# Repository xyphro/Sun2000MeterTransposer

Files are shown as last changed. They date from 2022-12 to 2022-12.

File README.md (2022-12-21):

# Sun2000MeterTransposer

-> Enable other Smartmeters like SDM630 to connect to Huawei Sun2000 and look like DTSU-666.

This was my solution to address the fact, that DTSU-666 and its variants availability was "null".

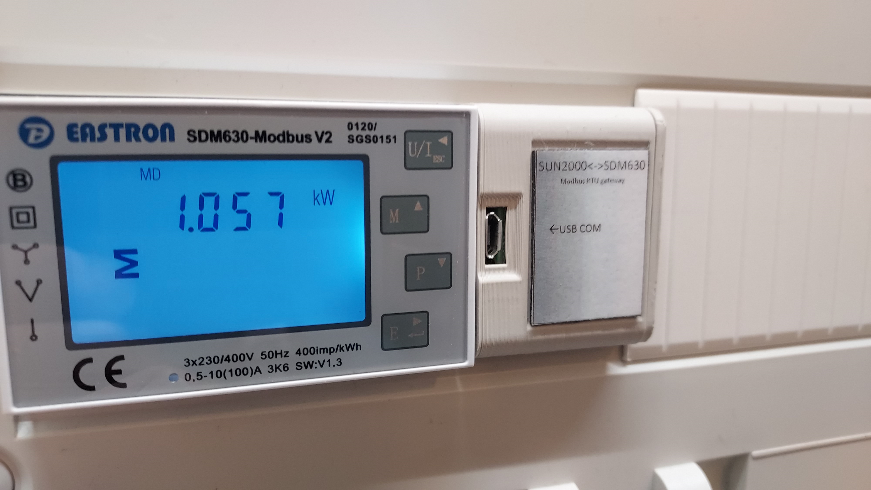
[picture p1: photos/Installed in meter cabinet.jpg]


It works rock solid since several months without a single interruption.

The project is based on RP2040 Raspberry pi Zero module. It will work on the Wifi variant too, but there is no network access enabled.

Note: I did not document the HW very well (yet), but want to share it still with the community. Build it at your own risk. The pinning of the 2 UART channels can be seen in s2kserver.py module (or schematic).

Warning: This project works with high voltage AC supply. You risk killing yourself, your family and friends, your pets. Take care and only work with line voltages when you are experienced in how much pain it causes to touch 230V :-)

# Folder structure

- hw: contains schematic / PCB in Eagle format.
- src: Micropython sourcecode - can be directly uploaded to RP2040 module using e.g. Thony IDE
- DinRainHousing: STL files for the 3D printed Dinrail housing
- photos: Some pictures of the actual build as inspiration

# Adjustments to other meters

Copy file sdm630.py and rename it to your meter name. Adjust it, such that the equivalent registers of your meter are read out and written to s2k module registers.
Within file s2kserver.py:
- You might need to change the UART settings like baudrate, parity in s2kserver during instatiation of uModBusSerial module.
- change ```from sdm630 import *``` to your module name

# Sourcecode orientation

main.py purpose is only to start s2kserver.py.
s2kserver instantiates 2 threads to server requests from Sun2000 inverter and poll SDM630 meter continously.

# Credits

Credits go to:
- uModbus [1] project. I changed the file slightly and included all dependencies within the src folder. Main modifications were done for speed/latency purposes
- DTSU666-Modbus [2] project: This project was of major support for the idea and to get register details. 
- GitHub user salakrzy
- Kai for testing it in endless debug sessions remotely whilr I was still busy ibstalling my solar installation and could not test myself
- Radek for making and providing his Chint DTSU666 module

# Compatibility

Tested with sun2000 3 phase 10kW inverters and proven working with spc147 and 148 firmware versions. As of now there is no newer one available.

# Updates

## 21st December 2022: 

Github user Radek made a module to support CHINT DTSU666 electricity meter (dtsu666.py). Thanks a lot for sharing it!

To make use of it adjust the settings within the user configurable settings in the file s2kserver.py.

Note that Chint DTSU666 usually uses those UART settings unless you configured it manually differently:

```
METER_UART_BAUDRATE = 9600
METER_UART_BITS     = 8
METER_UART_PARITY   = None
METER_UART_STOPBITS = 2
```

[1] https://github.com/pycom/pycom-modbus/tree/master/uModbus

[2] https://github.com/elfabriceu/DTSU666-Modbus

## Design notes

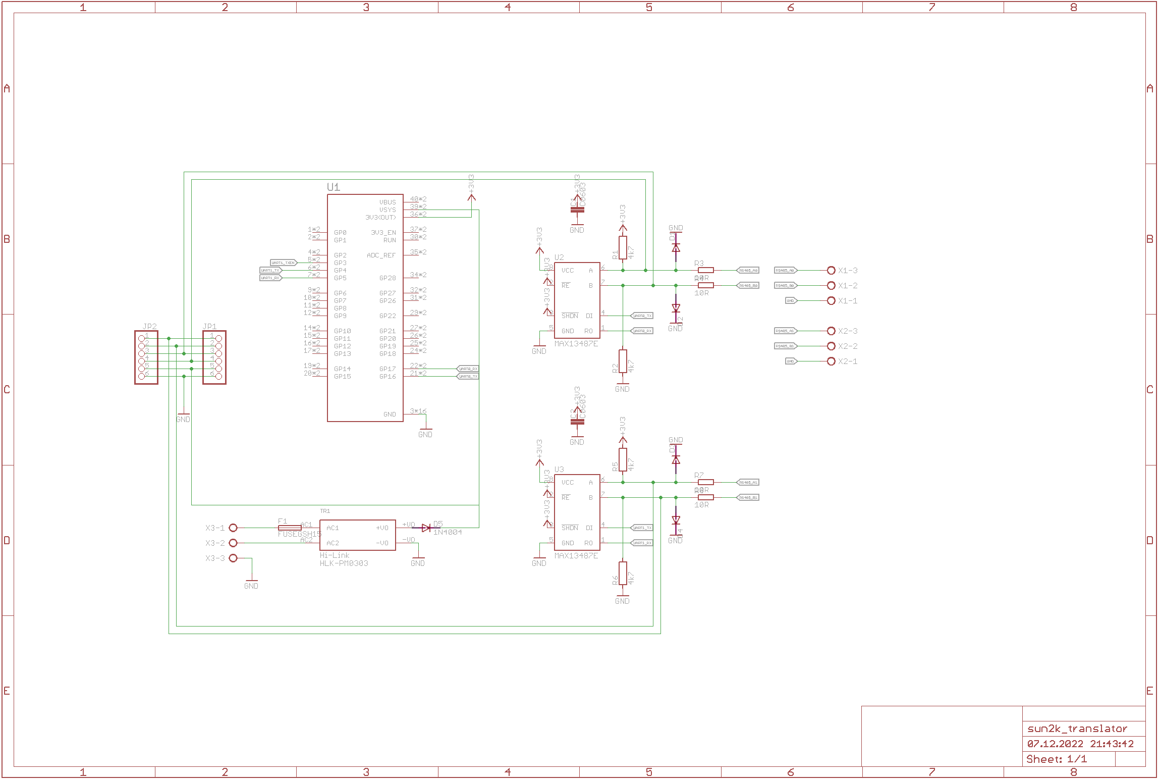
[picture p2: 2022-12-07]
hw/Schematic.png

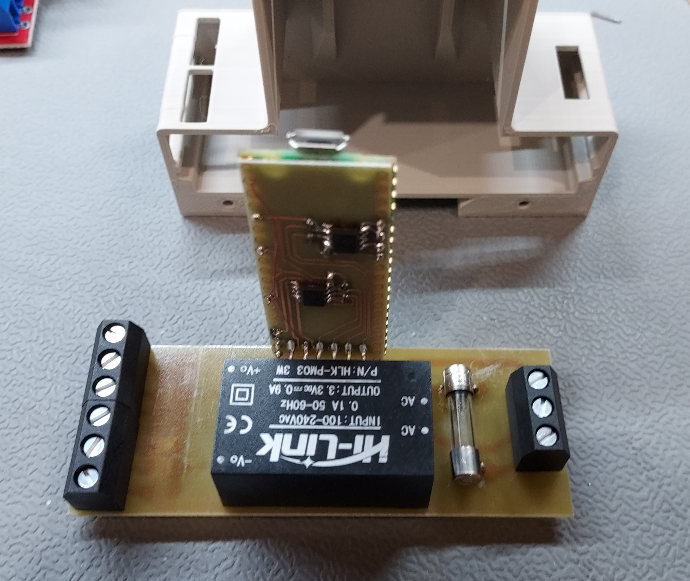
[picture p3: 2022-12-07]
photos/pcb1.jpg

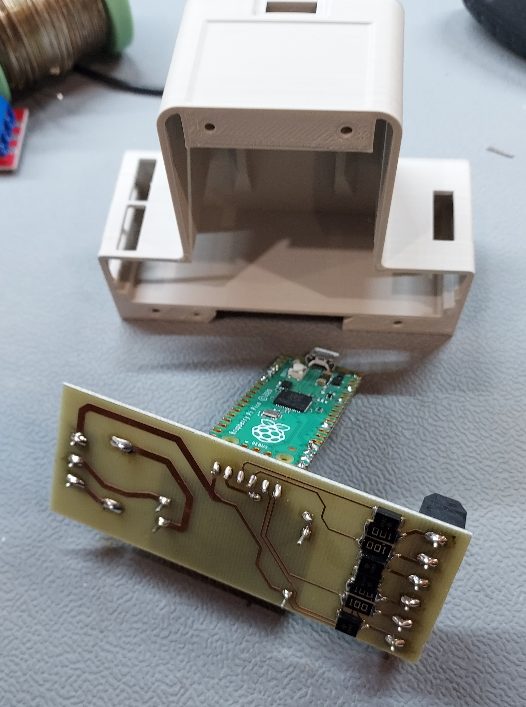
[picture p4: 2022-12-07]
photos/pcb2.jpg

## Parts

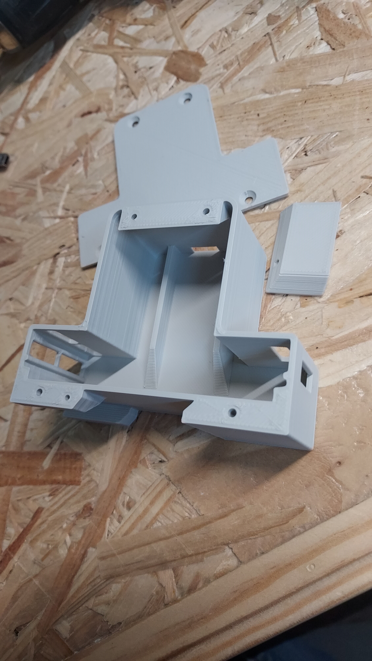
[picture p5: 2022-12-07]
photos/3D printed parts.jpg

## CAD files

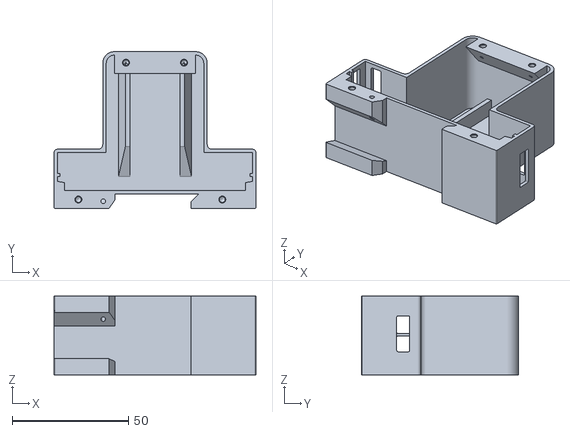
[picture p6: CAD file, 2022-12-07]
DinRailHousing/DinRail1.stl
87.0 x 67.5 x 34.0

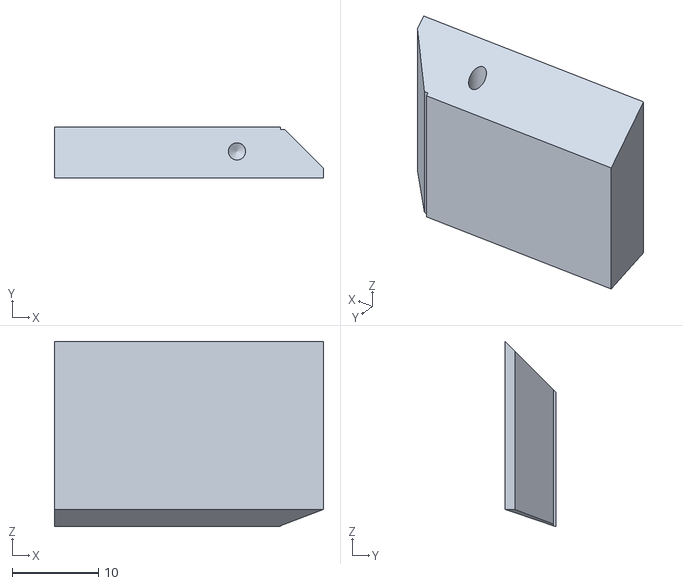
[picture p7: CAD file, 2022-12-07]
DinRailHousing/DinRail3.stl
31.2 x 5.87 x 21.5

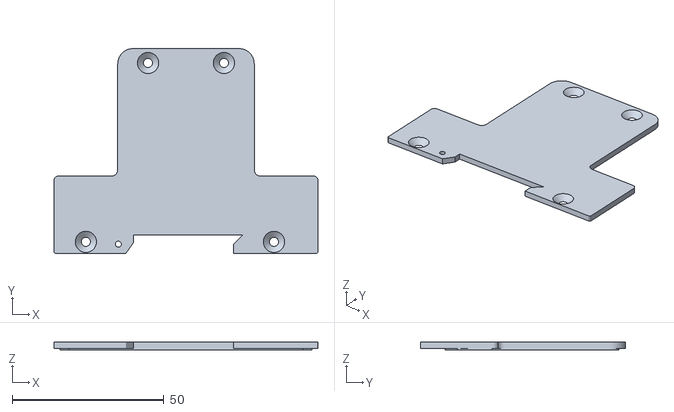
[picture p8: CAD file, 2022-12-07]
DinRailHousing/DinRail2.stl
87.0 x 67.5 x 2.50

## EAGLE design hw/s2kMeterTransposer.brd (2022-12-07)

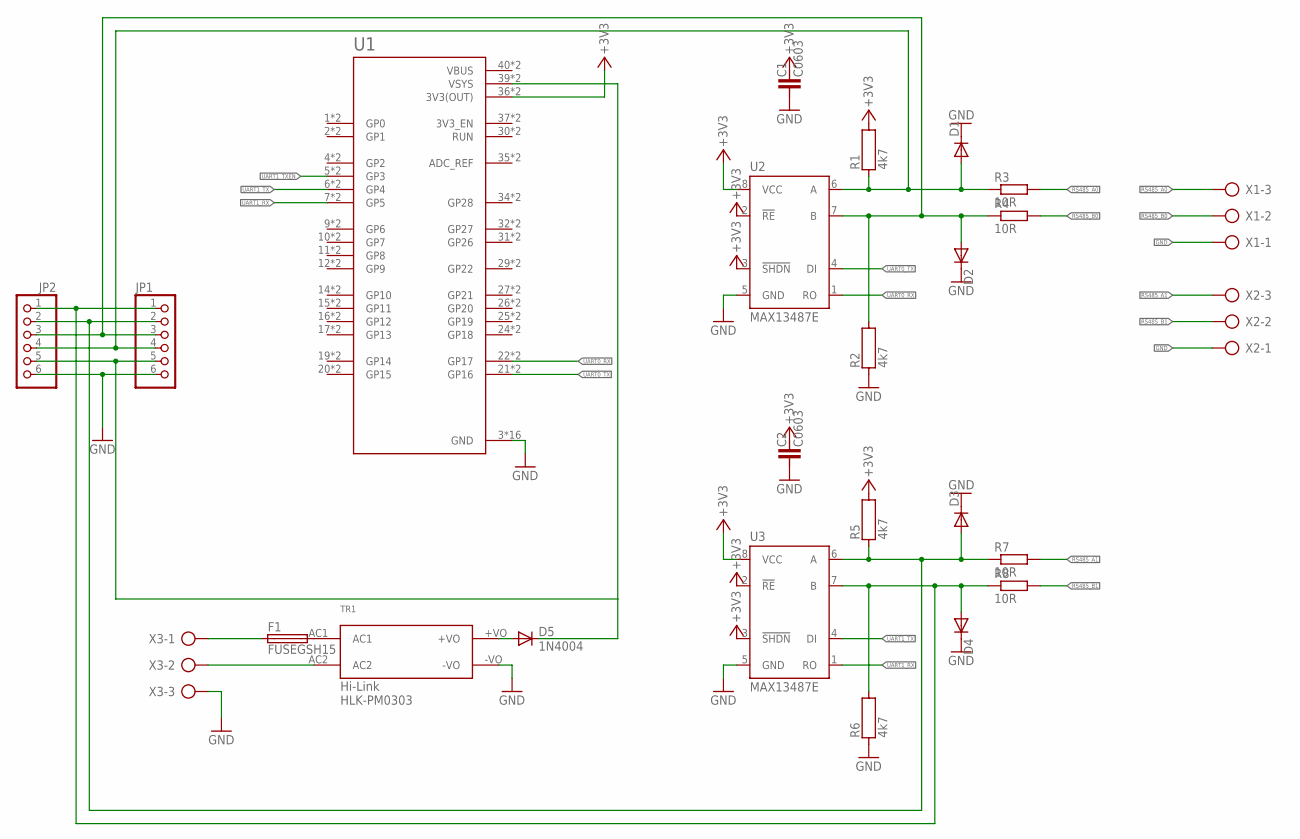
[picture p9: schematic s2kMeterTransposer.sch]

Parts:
C1, C2: C0603
D1, D2, D3, D4: DIODE-DO-214AC; DO-214AC
D5: 1N4004; DO41-10
F1: FUSEGSH15; GSH15
JP1: PINHD-1X6; 1X06
JP2: PINHD-1X6/90; 1X06/90
R1, R2, R5, R6: 4k7; R0603
R3, R4, R7, R8: 10R; R2010
TR1: HYX2018013001158
U1: RASPBERRY_PICO-NO_DEBUG; PICO-PKG-NO_DEBUG
U2, U3: MAX13487E; SO08
X1, X2, X3: AK500/3

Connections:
+3V3: C1.2, C2.2, R1.2, R5.2, U1.36 (3V3(OUT)), U1.P$36 (3V3(OUT)), U2.2 (!RE), U2.3 (!SHDN), U2.8 (VCC), U3.2 (!RE), U3.3 (!SHDN), U3.8 (VCC)
GND: C1.1, C2.1, D1.C, D2.C, D3.C, D4.C, JP1.6, JP2.6, R2.1, R6.1, TR1.-VO, U1.3 (GND), U1.8 (GND), U1.13 (GND), U1.18 (GND), U1.23 (GND), U1.28 (GND), U1.33 (GND), U1.38 (GND), U1.P$3 (GND), U1.P$8 (GND), U1.P$13 (GND), U1.P$18 (GND), U1.P$23 (GND), U1.P$28 (GND), U1.P$33 (GND), U1.P$38 (GND), U2.5 (GND), U3.5 (GND), X1.1, X2.1, X3.3
unnamed: D2.A, JP1.3, JP2.3, R2.2, R4.1, U2.7 (B)
unnamed: D1.A, JP1.4, JP2.4, R1.1, R3.1, U2.6 (A)
unnamed: D4.A, JP1.1, JP2.1, R6.2, R8.1, U3.7 (B)
unnamed: D3.A, JP1.2, JP2.2, R5.1, R7.1, U3.6 (A)
unnamed: F1.2, TR1.AC1
unnamed: F1.1, X3.1
unnamed: TR1.AC2, X3.2
unnamed: D5.A, TR1.+VO
unnamed: D5.C, JP1.5, JP2.5, U1.39 (VSYS), U1.P$39 (VSYS)
RS485_A0: R3.2, X1.3
RS485_A1: R7.2, X2.3
RS485_B0: R4.2, X1.2
RS485_B1: R8.2, X2.2
UART0_RX: U1.22 (GP17), U1.P$22 (GP17), U2.1 (RO)
UART0_TX: U1.21 (GP16), U1.P$21 (GP16), U2.4 (DI)
UART1_RX: U1.7 (GP5), U1.P$7 (GP5), U3.1 (RO)
UART1_TX: U1.6 (GP4), U1.P$6 (GP4), U3.4 (DI)
UART1_TXEN: U1.5 (GP3), U1.P$5 (GP3)
VBUS: U1.40 (VBUS), U1.P$40 (VBUS)

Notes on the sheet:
Hi-Link HLK-PM0303

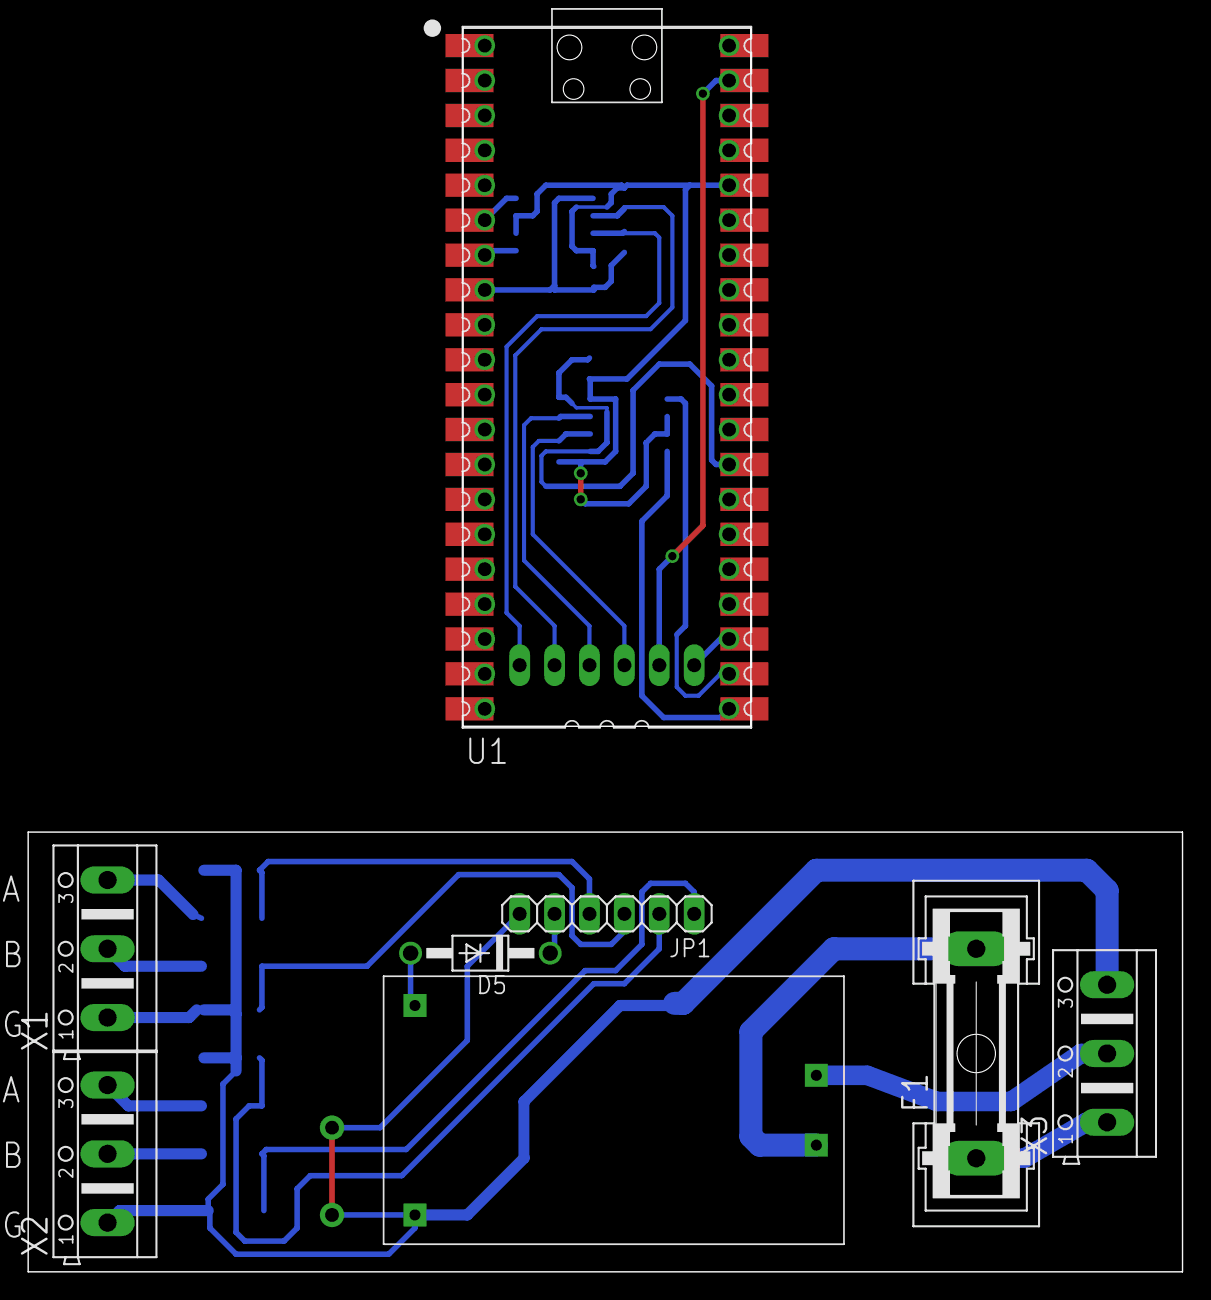
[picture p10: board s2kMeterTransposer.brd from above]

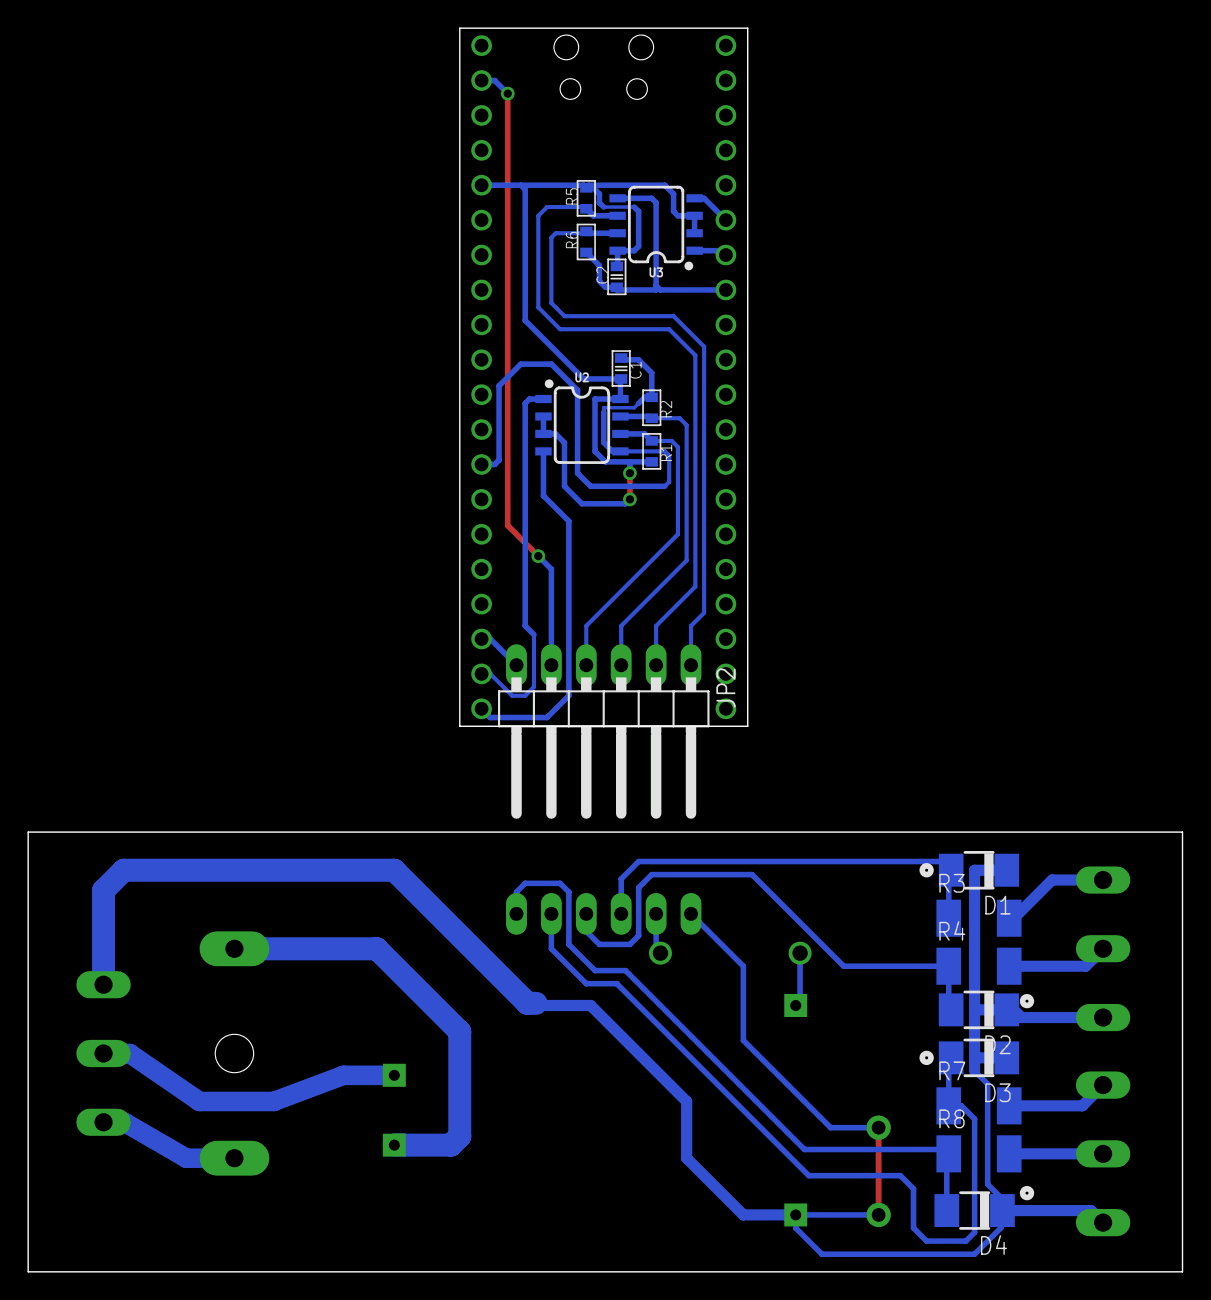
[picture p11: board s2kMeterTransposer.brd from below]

Board: 2 copper layers, 84.0 x 90.5 mm, 25 parts (17 on the bottom side), 21 nets.

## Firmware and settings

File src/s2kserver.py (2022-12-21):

from machine import UART, Pin
import sys
sys.path.append('modbus')
from uModBusServer import *
from uModBusSerial import *
import _thread
from sun2000 import *


# ##########################################################################################
# Start of user configurable settings
# ##########################################################################################

# Adjust below settings to be the same as for your electricity meter Modbus RS485 settings 
METER_UART_BAUDRATE = 9600
METER_UART_BITS     = 8
METER_UART_PARITY   = None
METER_UART_STOPBITS = 1

# Below sdm630 import handles communication with an SDM630 electricity meter.
# Simply implement your own module (see sdm630.py) to handle other electricity meters and import it here!
from sdm630 import *

# Uncomment below line to select chint DTSU666 meter. Don't forget to comment above codeline too - only one of them should be active.
#from dtsu666 import *


# ##########################################################################################
# End of user configurable settings
# ##########################################################################################



# This callback function gets called by the modbus server for every register which has to be read.
def readRegister(server, starting_addr, quantity):
    #print('read request received. starting_addr=%d, quantity=%d' % (starting_addr, quantity))
    while quantity > 0:
        try:
            value = s2k.registers[starting_addr]
        except:
            value = 0            
        server.sendreg(value)
        starting_addr = starting_addr + 1
        quantity = quantity - 1


# The server thread is run in background and handles queries from an external Sun2000 modbus client
def serverthread():
    while True:
        try:
            server.receive()
        except Exception as e:
            print('serverthread exception occured: '+str(e))
            pass;

# Below 2 lines instantiate a modbus server and client. Adjust pins and uart settings according to your board design
server = uModBusServer(slave_id=11, uart_id = 0, baudrate=9600, data_bits=8, stop_bits=1, parity=None, pins=(Pin(16), Pin(17)), ctrl_pin=None, loopbacked=True, callbackfunction=readRegister)
client = uModBusSerial(uart_id = 1, baudrate=METER_UART_BAUDRATE, data_bits=METER_UART_BITS, stop_bits=METER_UART_STOPBITS, parity=METER_UART_PARITY, pins=(Pin(4), Pin(5)), ctrl_pin=3, loopbacked=True)
s2k = sun2000()
mtr = meter(client, s2k)

_thread.start_new_thread(serverthread, ())

# Below thread does continously read your electricity meter data and push them to sun2000 module registers
while True:
    try:
        mtr.updateRegisters()
    except Exception as e:
        print('clientthread exception occured: '+str(e))
        pass;
    

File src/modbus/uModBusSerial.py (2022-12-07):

#Source: https://github.com/pycom/pycom-modbus/tree/master/uModbus (2018-07-16)
#This file has been modified and differ from its source version.

import uModBusFunctions as functions
import uModBusConst as Const
from machine import UART
from machine import Pin
import struct
import time
import machine

class uModBusSerial:

    def __init__(self, uart_id, baudrate=9600, data_bits=8, stop_bits=1, parity=None, pins=None, ctrl_pin=None, loopbacked=True):
        pinsLen=len(pins)
        if pins==None or pinsLen<2 or pinsLen>4 or pinsLen==3:
            raise ValueError('pins should contain pin names/numbers for: tx, rx, [rts, cts]')
        tx=pins[0]
        rx=pins[1]
        if pinsLen==4:
            rts=pins[2]
            cts=pins[3]
            self._uart = UART(uart_id, baudrate=baudrate, bits=data_bits, parity=parity, \
                          stop=stop_bits, timeout=100, timeout_char=2, tx=tx, rx=rx, rts=rts, cts=cts, rxbuf=256)
        else:
            self._uart = UART(uart_id, baudrate=baudrate, bits=data_bits, parity=parity, \
                            stop=stop_bits, timeout=100, timeout_char=2, tx=tx, rx=rx, rxbuf=256)
        #self._uart = UART(uart_id, baudrate=baudrate, bits=data_bits, parity=parity, \
        #                  stop=stop_bits, timeout_chars=10, pins=pins)
        if ctrl_pin is not None:
            self._ctrlPin = Pin(ctrl_pin, mode=Pin.OUT)
            self._ctrlPin(0)
        else:
            self._ctrlPin = None
        self.char_time_ms = (1000 * (data_bits + stop_bits + 2)) / baudrate
        self.loopbacked = loopbacked

    def _calculate_crc16(self, data):
        crc = 0xFFFF

        for char in data:
            crc = (crc >> 8) ^ Const.CRC16_TABLE[((crc) ^ char) & 0xFF]

        return struct.pack('<H',crc)

    def _bytes_to_bool(self, byte_list):
        bool_list = []
        for index, byte in enumerate(byte_list):
            bool_list.extend([bool(byte & (1 << n)) for n in range(8)])

        return bool_list

    def _to_short(self, byte_array, signed=True):
        response_quantity = int(len(byte_array) / 2)
        fmt = '>' + (('h' if signed else 'H') * response_quantity)

        return struct.unpack(fmt, byte_array)
    
    def _to_float(self, byte_array):
        response_quantity = int(len(byte_array) / 4)
        fmt = '>' + ('f' * response_quantity)
        
        return struct.unpack(fmt, byte_array)

    def _exit_read(self, response):
        if response[1] >= Const.ERROR_BIAS:
            if len(response) < Const.ERROR_RESP_LEN:
                return False
        elif (Const.READ_COILS <= response[1] <= Const.READ_INPUT_REGISTER):
            expected_len = Const.RESPONSE_HDR_LENGTH + 1 + response[2] + Const.CRC_LENGTH
            if len(response) < expected_len:
                return False
        elif len(response) < Const.FIXED_RESP_LEN:
            return False

        return True

    def _uart_read(self):
        response = bytearray()
        starttime = time.ticks_ms()        
        for x in range(1, 40):
            if self._uart.any():
                response.extend(self._uart.read())
                #response.extend(self._uart.readall())
                # variable length function codes may require multiple reads
                if self._exit_read(response):
                    break            
            time.sleep(0.05)

        return response

    def _send_receive(self, modbus_pdu, slave_addr, count, expectedlen = 255):
        serial_pdu = bytearray()
        serial_pdu.append(slave_addr)
        serial_pdu.extend(modbus_pdu)

        crc = self._calculate_crc16(serial_pdu)
        serial_pdu.extend(crc)

        # flush the Rx FIFO
        if self._uart.any():
            self._uart.read()
            print('flushed')
        if self._ctrlPin:
            self._ctrlPin(1)
        self._uart.write(serial_pdu)
        if self._ctrlPin:
            time.sleep_ms(int(1 + len(serial_pdu) * self.char_time_ms))
            self._ctrlPin(0)
        if self.loopbacked:
            self._uart.read(len(serial_pdu))

        response = self._uart.read(expectedlen)
        #response = []
        #while len(response) < expectedlen:
        #    response.extend(self._uart.read(expectedlen-len(response)))
        
        print(response)
            
            
        #response = self._uart_read()
        print(expectedlen, response)

        
        return self._validate_resp_hdr(response, slave_addr, modbus_pdu[0], count)

    def _validate_resp_hdr(self, response, slave_addr, function_code, count):

        if len(response) == 0:
            raise OSError('no data received from slave')

        resp_crc = response[-Const.CRC_LENGTH:]
        expected_crc = self._calculate_crc16(response[0:len(response) - Const.CRC_LENGTH])
        if (resp_crc[0] != expected_crc[0]) or (resp_crc[1] != expected_crc[1]):
            raise OSError('invalid response CRC')

        if (response[0] != slave_addr):
            raise ValueError('wrong slave address')

        if (response[1] == (function_code + Const.ERROR_BIAS)):
            raise ValueError('slave returned exception code: {:d}'.format(response[2]))

        hdr_length = (Const.RESPONSE_HDR_LENGTH + 1) if count else Const.RESPONSE_HDR_LENGTH

        return response[hdr_length : len(response) - Const.CRC_LENGTH]

    def read_coils(self, slave_addr, starting_addr, coil_qty):
        modbus_pdu = functions.read_coils(starting_addr, coil_qty)

        resp_data = self._send_receive(modbus_pdu, slave_addr, True)
        status_pdu = self._bytes_to_bool(resp_data)

        return status_pdu

    def read_discrete_inputs(self, slave_addr, starting_addr, input_qty):
        modbus_pdu = functions.read_discrete_inputs(starting_addr, input_qty)

        resp_data = self._send_receive(modbus_pdu, slave_addr, True)
        status_pdu = self._bytes_to_bool(resp_data)

        return status_pdu

    def read_holding_registers(self, slave_addr, starting_addr, register_qty, signed=True):
        modbus_pdu = functions.read_holding_registers(starting_addr, register_qty)

        resp_data = self._send_receive(modbus_pdu, slave_addr, True, expectedlen = register_quantity*2+5)
        register_value = self._to_short(resp_data, signed)

        return register_value
    
    def read_input_registers(self, slave_addr, starting_address, register_quantity, isfloat=True):
        starting_address = starting_address - 30001
        if isfloat:
            register_quantity = register_quantity * 2
        modbus_pdu = functions.read_input_registers(starting_address, register_quantity)

        resp_data = self._send_receive(modbus_pdu, slave_addr, True, expectedlen = register_quantity*2+5)
        if isfloat:
            register_value = self._to_float(resp_data)
        else:
            register_value = self._to_short(resp_data, False)

        return list(register_value)
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

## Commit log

2022-12-07 Add STL files for 3D printed housing
    [DinRail1.stl, DinRail2.stl, DinRail3.stl]
2022-12-07 Add Eagle layout and schematic
    [s2kMeterTransposer.brd, s2kMeterTransposer.sch]
